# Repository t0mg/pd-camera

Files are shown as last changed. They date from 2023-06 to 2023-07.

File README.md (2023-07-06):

# PD-Camera project

PD-Camera is an unofficial, experimental accessory for [Panic Inc.](https://panic.com/)'s [Playdate](https://play.date) handheld console, which as the name hopefully suggests allows the device to record pictures as well as animated gifs, in whopping  1-bit color and QVGA (320x240) resolution. Kind of similar to the [1998 accessory for that other monochrome handheld device](https://en.wikipedia.org/wiki/Game_Boy_Camera) (which has 2-bit color and fewer pixels).

> **This repository contains the hardware and firmware of the PD-Camera accessory. The source for the companion app that runs on the Playdate itself can be found [here](https://github.com/t0mg/pd-camera-app).**

Here's a one minute intro video (click to watch).

Watch the project's trailer video on YouTube (https://www.youtube.com/watch?v=sbAL9xYFmcQ)

And a four minute demo that was part of [Tiny Yellow Machine](https://www.youtube.com/@TinyYellowMachine)'s Playdate Community Direct. Goes a bit more into details and shows video recording (click to watch).

Longer demo introducing video feature, as part of the TYM Community Direct (https://youtu.be/dU_6qfiDft4?t=1531)

## Disclaimer

This project is 
- not affiliated with nor endorsed by [Panic Inc.](https://panic.com/), 
- highly experimental,
- very hacky,
   - oh so hacky.

While I crashed my own Playdate countless times working on this, and it has survived so far, I cannot be held responsible for any damage, data loss, bad selfie, pandemic, etc. that might occur to you while playing with this project. Use this at your own risk. Thanks ❤️.

## How does it work? Why does it exist?

For more context on how this project came to be, you can find its devlog [on Playdate's Dev forum](https://devforum.play.date/t/playdate-oneil-camera/11043) and a deep dive into how it all works [here](dive.md).

Otherwise read on for an overview of each part.

## Hardware

### Configurations

The Playdate can be attached to the camera accessory in three distinct configurations: **cover**, **camera**, and **selfie**.

The accessory is holding onto the Playdate with small magnets. In **camera mode**. A USB C cable plugs into the console and disappears inside a "chin" in the bottom of the accessory. In **cover mode** the Playdate can be unplugged and flipped with its screen facing backwards, in order to lay flat and protect it during transport.

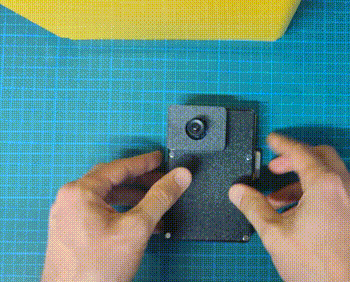
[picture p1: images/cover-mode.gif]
Transforming from cover mode to camera mode


The Playdate can also be fitted on the back of the accessory, without unplugging the cable, allowing to switch the camera to **selfie mode** (the companion app has a mirror option so it doesn't feel awkward). Additional magnets are here to secure the console in this configuration too.

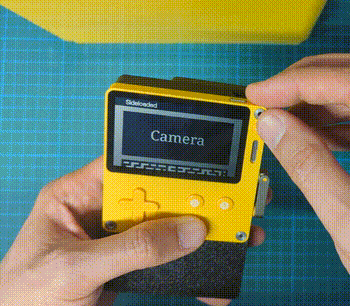
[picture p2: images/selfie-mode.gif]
Switching to selfie mode


### What's inside

The project is based on a [Teensy 4.1 microcontroller](https://www.pjrc.com/store/teensy41.html) that acts as a USB host to the Playdate and communicates with it over serial, including evaluating payloads in the Lua runtime (see [here](https://github.com/jaames/playdate-reverse-engineering/blob/main/usb/usb.md) for more details). The Teensy is also connected to an OV7670 camera module via its CMOS Sensor Interface (CSI) built into the IMXRT1062 MPU and using [this dedicated library](https://github.com/mjborgerson/OV7670). The images produced are 1-bit, QVGA (320x240 pixels) and recorded directly in the Playdate's filesystem. The Teensy takes care of dithering the images in various ways before sending them to the Playdate.

A battery, custom PCB and a custom 3D-printable case complete the hardware ([gerber](hardware/pcb) and [stl](hardware/case) files are provided in this repository).

For the detailed bill of material and assembly instructions, hop over to the [hardware folder](/hardware/).

## Firmware

To flash the Teensy microcontroller with the project's firmware, you'll need the [Teensy loader application](https://www.pjrc.com/teensy/loader.html). 

If you don't want to modify the source, you can directly grab a prebuilt `firmware.hex` file from the repository's [releases](https://github.com/t0mg/pd-camera/releases). Otherwise, read on to build your own.

## Companion app

The app that needs to be sideloaded onto the Playdate is located in a [separate repository](https://github.com/t0mg/pd-camera-app).

### Building

This project uses [PlatformIO](https://platformio.org/) to manage dependencies and build toolchain, see [platformio.ini](platformio.ini).

The source code comprises a single, messy [main.cpp](src/main.cpp) file, which relies on a few excellent libraries listed below.

## Credits

Dependencies
  -	[USBHost_t36](https://github.com/PaulStoffregen/USBHost_t36) by 
  [PaulStoffregen](https://github.com/PaulStoffregen)
  - [OV7670](https://github.com/mjborgerson/OV7670) by [mjborgerson](https://github.com/mjborgerson)
  - [dithering_halftoning](https://github.com/deeptronix/dithering_halftoning) by [deeptronix](https://github.com/deeptronix)

Made possible by
- https://github.com/jaames/playdate-reverse-engineering by [jaames](https://github.com/jaames)

 ----

 Playdate is © [Panic Inc.](https://panic.com/) - this project isn't affiliated with or endorsed by them in any way (just like [that one](https://github.com/jaames/playdate-reverse-engineering))

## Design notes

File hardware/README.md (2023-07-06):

This folder contains all files and instruction necessary to build the PD-Camera hardware.

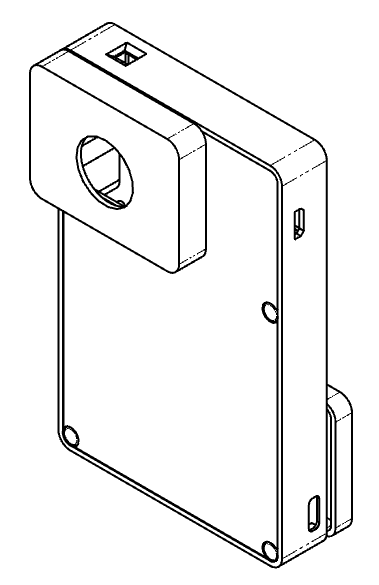
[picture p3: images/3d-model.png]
A drawing of the case from the OnShape project


## Bill of materials

Not counting the Playdate, the most expensive part here is the Teensy which retails for about 50€. The camera sensor is well under 10€. The PCB price will depend on the manufacturer but you can go very cheap too. Overall the whole project should cost around 100€ to build.

|Item| Quantity|Notes
|---|---|---|
|Custom PCB|1|Order from [JLCPCB](https://jlcpcb.com) or [OSH Park](https://oshpark.com/) see Gerber files
|Teensy 4.1 microcontroller| 1|[PJCRC store](https://www.pjrc.com/store/teensy41.html)
|OV7670 camera module|1|[Example (amazon.fr)](https://www.amazon.fr/dp/B07V1FCLXG?) ⚠️ these are AZDelivery brand. I found that similar boards with identical pinout sometimes differ in the orientation of the sensor and will not be compatible out of the box.
|Male headers, 24 pins |2 |0.1 inch (2.54 mm) spacing, for the Teensy
|Male headers,  4 or 5 pins |1 |0.1 inch (2.54 mm) spacing, for the Teensy's USB host port
|Female headers, 9pins | 2 | 0.1 inch (2.54 mm) spacing, for the camera module, to be cut from a standard length header
|Resistor 4k Ohm, through hole|2|
|Toggle switch SK12D07|1|
|Booster/charger USB C|1| The case is designed to fit this specific one from [aliexpress (5PCS 5V 2A USB)](https://a.aliexpress.com/_Ez5FiBT). For others you'll need to modify the 3D model before printing.
|3.7v LiPo battery|1| Should fit in the case (max size approx. 55 x 66 x 10 mm). I used a 5000 mAh battery I extracted from [this pack (amazon.fr)](https://www.amazon.fr/dp/B082PPR281).
|Neodymium magnets 5x5mm|8| Will hold the Playdate securly in place, [example (amazon.fr)](https://www.amazon.fr/dp/B00TACGMJW)
|Angled USB C to USB A cable|1|25 cm minimum; [example (amazon.fr)](https://www.amazon.fr/dp/B07H95NY5Y)
|PETG filament for the 3D printed parts 🙂|
|Some wires, solder...|
| *Optional:* CS mount & CS lenses || Read below

### CS and M12 mounts

Given that OV7670 boards are so cheap, I got 5 which allowed me to experiment with various  mounts and lenses. The case makes it deliberately easy to swap out the entire sensor board so you could have several with each a different lens and/or mount. Like a DSLR, except you also swap the sensor (no dust yay)!

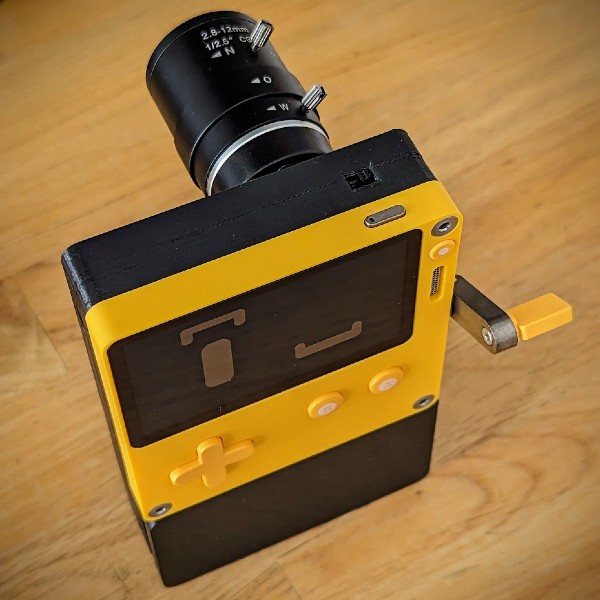
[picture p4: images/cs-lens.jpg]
A PD-Camera with a CS mount, telephoto lens. Admittedly looks cooler than with the default plastic lens.


Not all mounts are compatible and I had to do a bit of trial and error to find combinations of mounts and lenses that gives interesting results.

For the assembly pictured above, I bought [this CS mount (Aliexpress)](https://www.aliexpress.us/item/1005002055725137.html) and paired it with [this 2.8-12mm varifocal lens (Aliexpress)](https://www.aliexpress.us/item/3256802271188587.html).

Pay attention to the sensor distance of the mount. The first CS mount I purchased was too high, and the focal plane of the lenses hovered above the sensor, making it impossible to focus.

To replace the plastic mount that came with my OV7670 boards with this CS mount, I had to offset the screw holes a bit with a rotary tool, as pictured below.

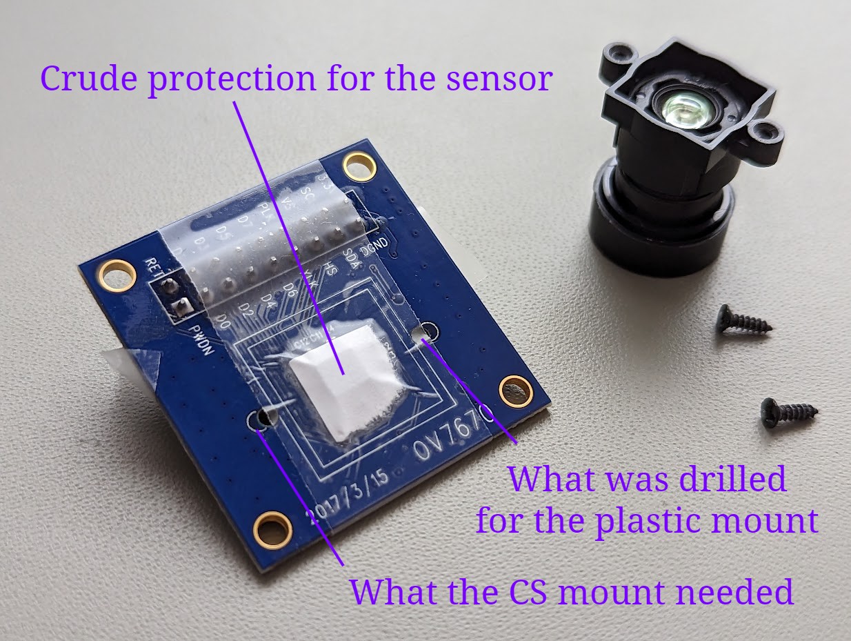
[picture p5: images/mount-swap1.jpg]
Fitting a new mount on one of my OV7670 boards
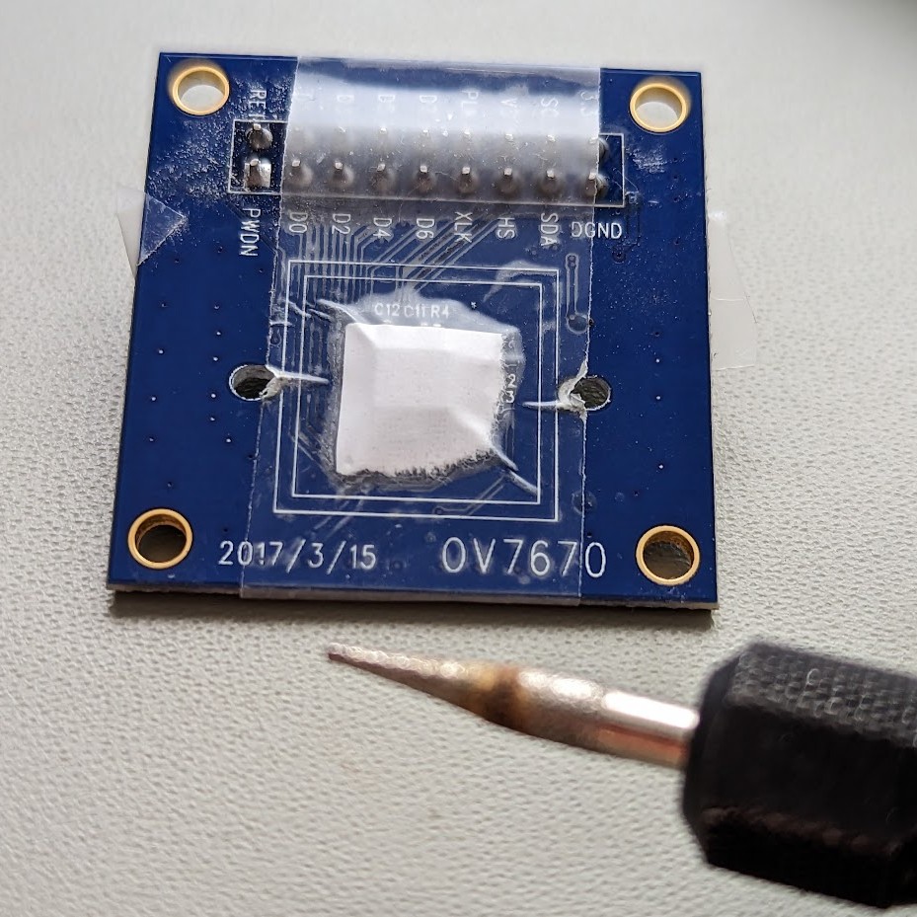
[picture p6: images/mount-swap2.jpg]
Making holes where the silkscreen suggests they should have been
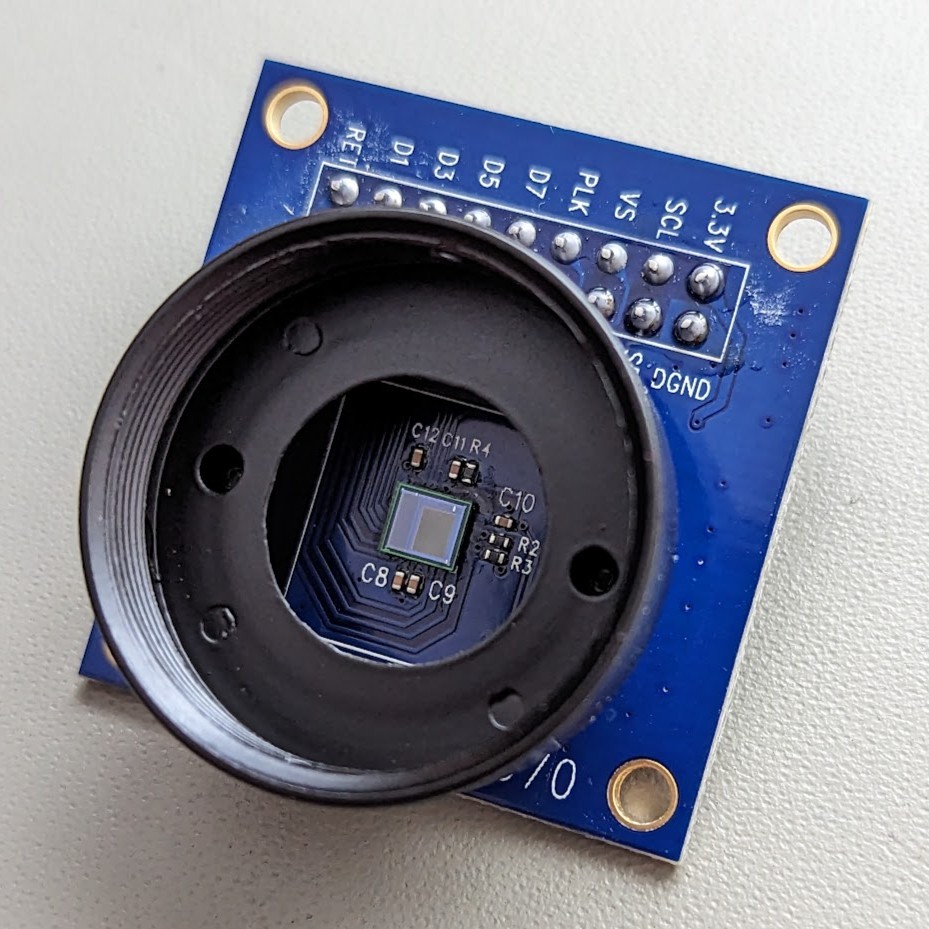
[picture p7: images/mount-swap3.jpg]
New CS mount secured to the sensor board
  

> Note: Pay attention to the orientation of the sensor. Some OV7670 boards have it swapped 90 or 180 degrees. The project is designed around this prarticular orientation. While 180 is fixable in the firmware code (setting register REG_MVFP), 90 degrees can not be used without significant modifications to the case and/or PCB.

These things being so cheap, I have plenty more to play with, including wide angle, a metal M12 mount and M12 lenses.

> // TODO: add more details here if there's interest, including example pictures and more references of tested lenses/mounts.

## Custom PCB

In order to keep the project small and easy to assemble, I designed a small PCB (my very first one so probably terrible, but it does work) to be paired with a custom designed case (which explains its peculiar shape). 

This is the wiring implemented by the PCB, it follows the documentation from the [OV7670 library](https://github.com/mjborgerson/OV7670) the project uses.

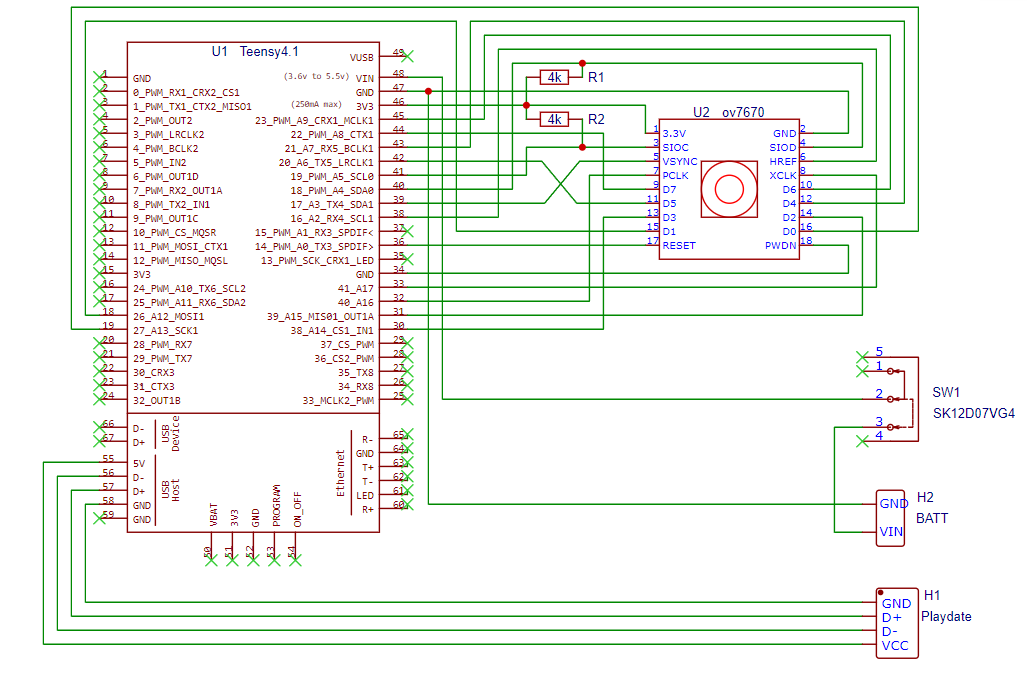
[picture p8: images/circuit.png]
Wiring circuit


The Gerber file for the PCB can be found [in the pcb folder](pcb/). It's 2 layer, standard thickness (1.57mm / 0.062 in). You can get one made from services such as [OSH Park](https://oshpark.com/) or [JLCPCB](https://jlcpcb.com/) for a few USD.

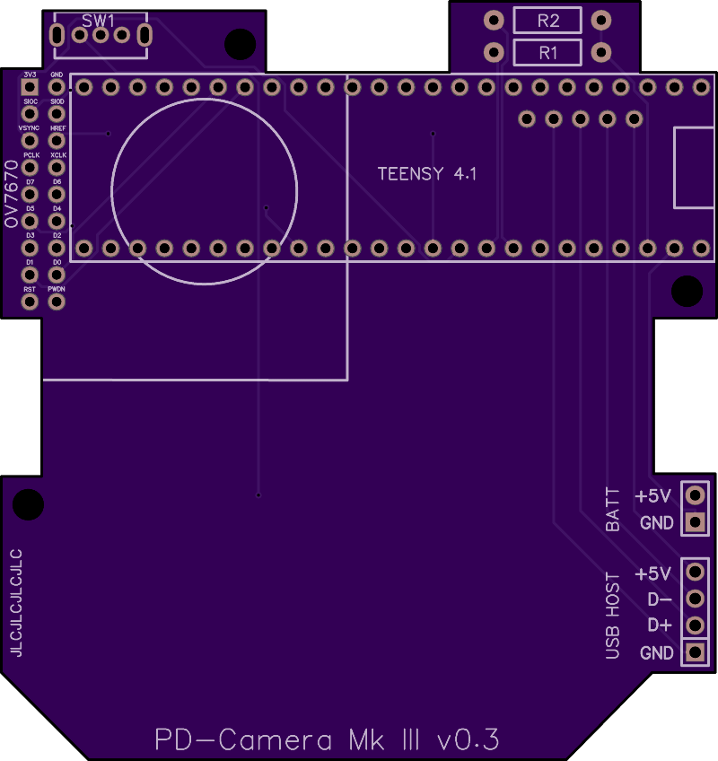
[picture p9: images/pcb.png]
A rendered view of the PCB


The large empty and seemingly useless part of the PCB is actually visible through button pockets on the face of the case, so the color you'll pick for the PCB matters. You can also customize the bottom silk screen with markings that will be visible when the Playdate is not installed!

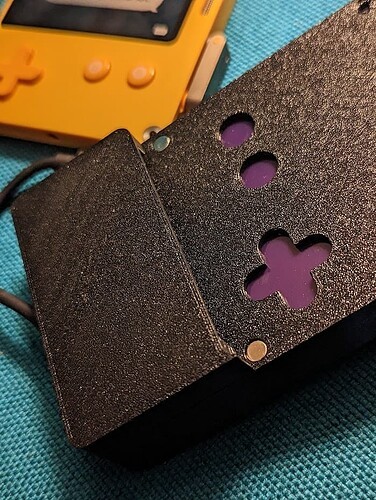
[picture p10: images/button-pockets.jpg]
A picture showing the button pockets on the 3D printed case and the purple PCB underneath


## Electronics assembly

Before do anything, plug the Teensy to a computer via its micro USB port and make sure the LED blinks, indicating the Teensy is working correctly. You can then take this opportunity to [flash the pd-camera firmware](../README.md#firmware).

> **WARNING**: If you want to be safe, you can now cut off the copper trace pictured below so the Teensy no longer draws power from its micro USB port. This eliminates the risk for the battery power to flow back into your computer if you connect the Teensy to it (in order to e.g. update the firmware).
>
> - If you cut the trace, you'll then need to turn the battery on even when plugging the Teensy's to a computer via micro USB, but it's foolproof. 
> - If you don't cut the bridge **you must always remember to turn the battery off**, as the Teensy will be powered via its micro USB port.
>
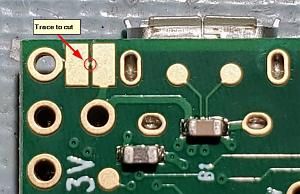
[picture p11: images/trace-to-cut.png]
Trace to cut to prevent micro USB from powering the Teensy (click for source)
> <p align="center"><a href="https://forum.pjrc.com/threads/70030-Teensy-4-1-Cut-pad-for-USB-location"></a/</p>  

### Soldering steps

Solder all male headers to the Teensy, including the 5 usb host pins. It helps to place the long headers on a breadboard to make sure the pins are straight (but you won't be able to do that with the USB Host pins because they're not aliged with the GPIO pins, so for these you can use the project's custom PCB).

Solder the 2 resistors and the toggle switch to the PCB.

Fit the Teensy flush onto the PCB, solder all pins and then cut off the protruding pins underneath, as short as possible.

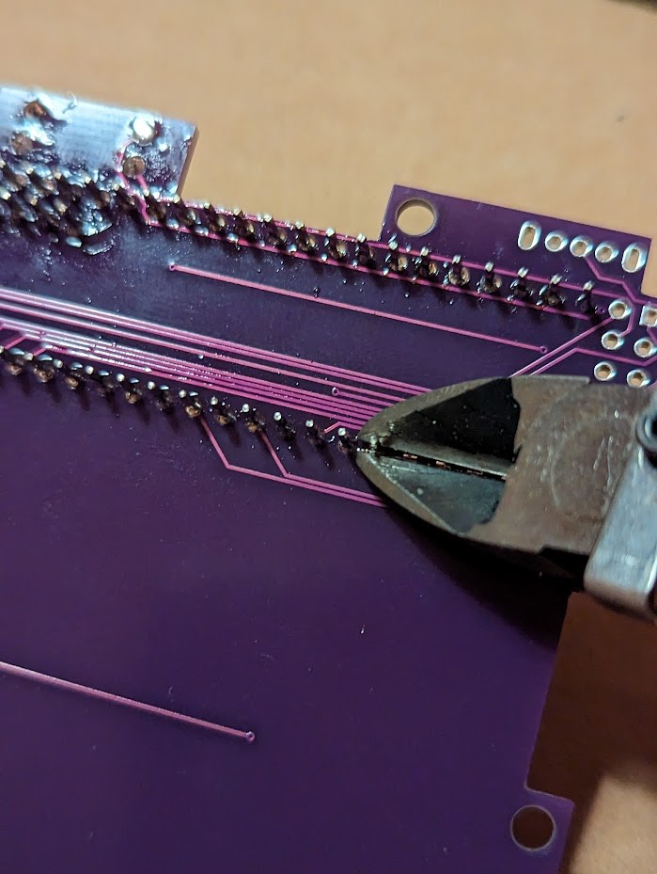
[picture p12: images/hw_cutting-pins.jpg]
Cutting Teensy pins flush


Cut 2 female header bars to 9 pins each and solder them to the PCB to create a makeshift connector for the OV7670 module.

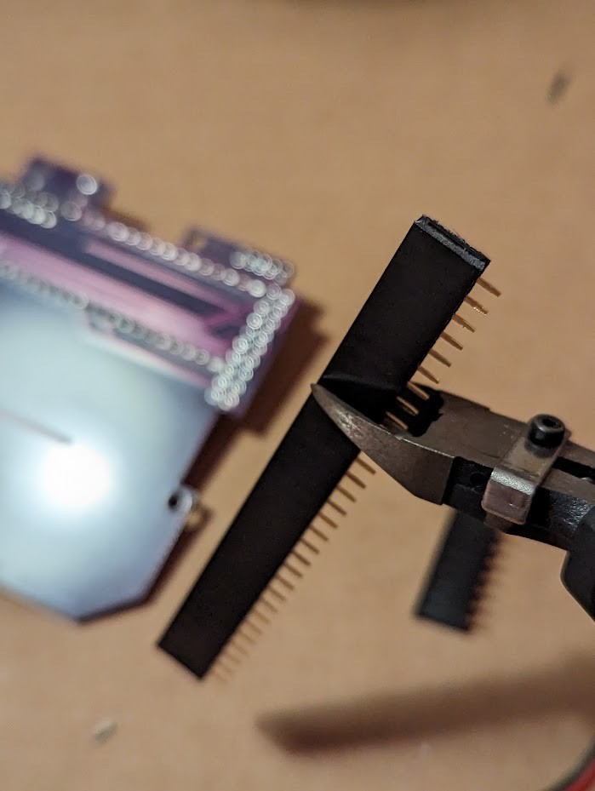
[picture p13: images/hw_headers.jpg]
Cutting female headers
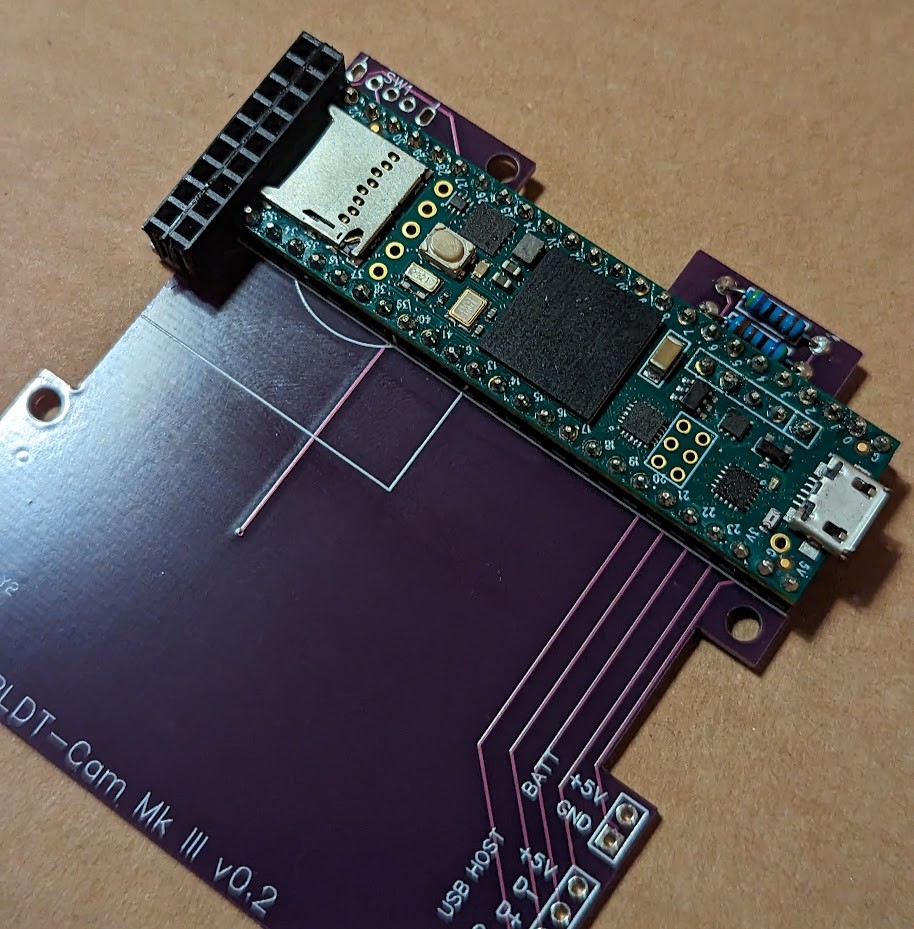
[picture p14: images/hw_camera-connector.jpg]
Camera module connector
 

Cut the angled USB C cable at about 25cm and discard the USB A connector. Strip and solder the 4 USB wires to the PCB (*usually*, red for +5v, white for D-, green for D+, and black for GND).

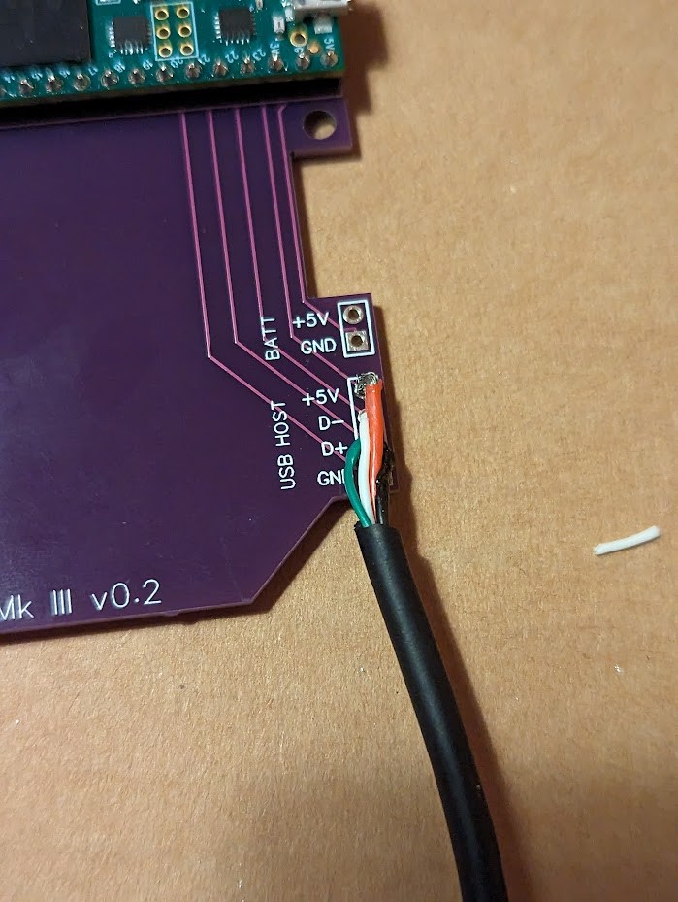
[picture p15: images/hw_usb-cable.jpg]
Soldering the USB Host cable


Solder BATT +5v and GND from the main PCB to the +5 and GND of the power circuit PCB with short wires, and finally solder the + and - battery pads of the power circuit to your LiPo battery. You can also do (or redo) this step after assembling the case in order to optimize your wiring.

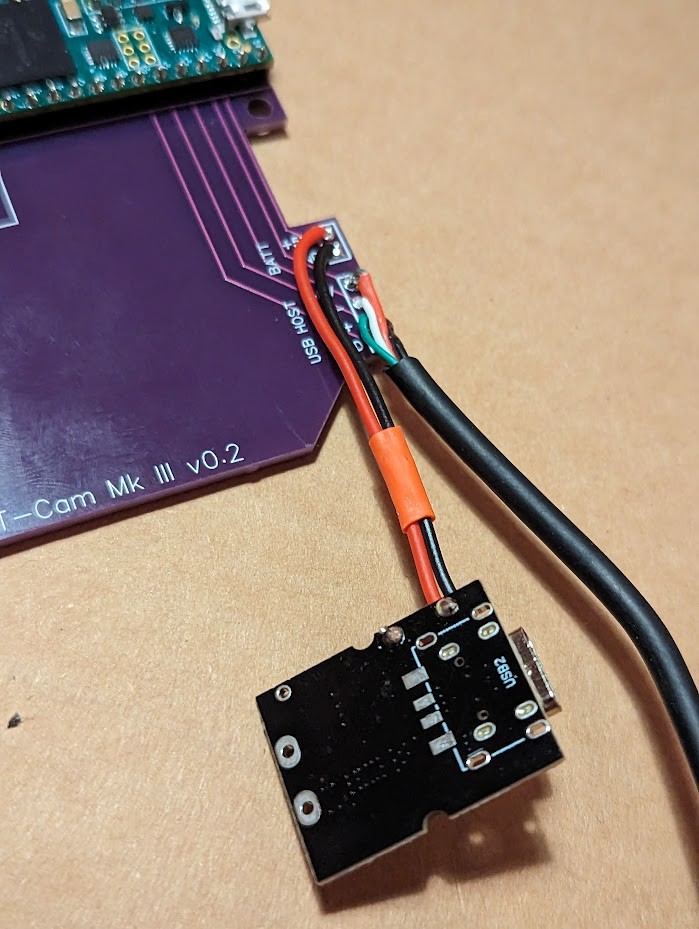
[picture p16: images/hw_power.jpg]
Soldering the power circuit


Almost done! Time to sideload the Playdate app (from [this repository](https://www.github.com/t0mg/pd-camera-app)) and test your circuit 🙂

Once you're confident with your solder joints, put your cutting pliers at work and make sure nothing protrudes underneath by more than a millimeter or so.

## 3D printed case

The case has 4 parts (body, chin, cover, camera cap) plus an optional flat spring that can help make the USB cable pop out of the chin. It was designed with OnShape (and Freecad orignally but I had to migrate).

Many iterations went into this design. The whole case could be more compact, especially with a smaller battery and fewer features. For example, without the selfie system the chin part could be reduced or removed, and the USB cable replaced with a simple dock connector. However I decided to prioritize versatility and ergonomics over compactness here.

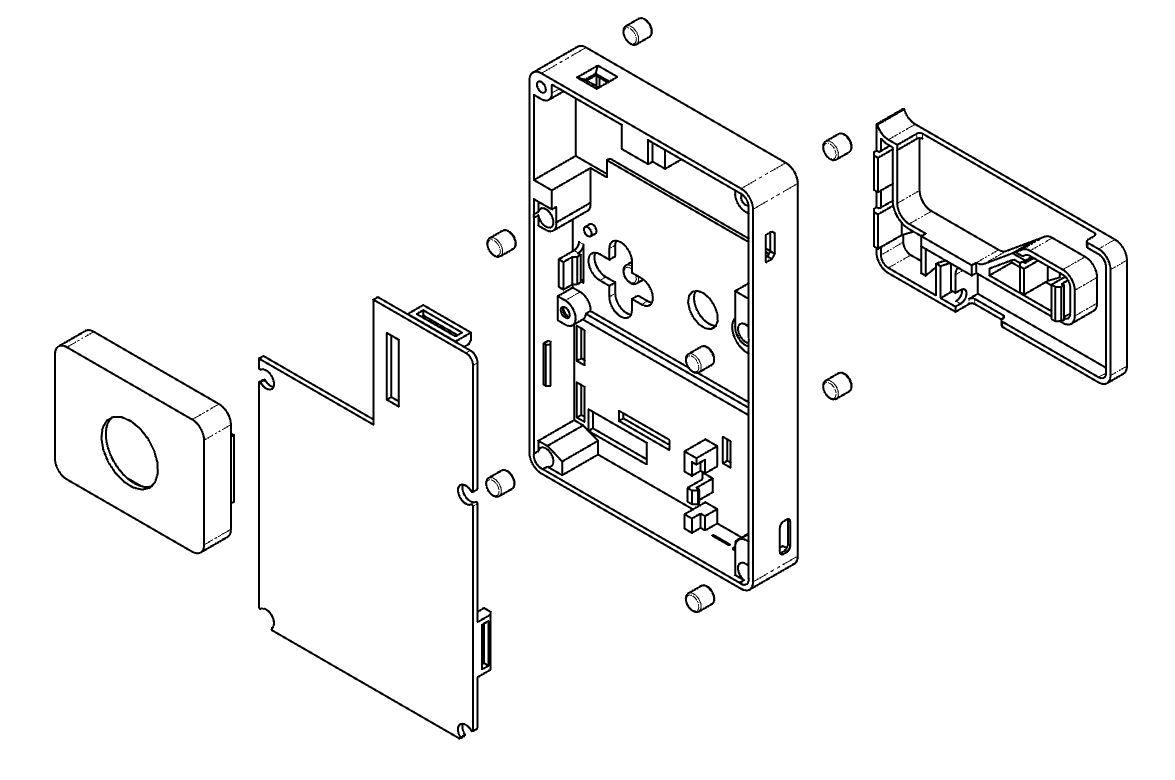
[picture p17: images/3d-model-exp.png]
Exploded view from the OnShape project showing all the parts


### Printing instructions

You can find the STL files [here](/hardware/case/). All the parts can be printed in one go on a Prusa Mk3S, in PETG at 0.2mm Speed mode, default settings. They were designed to print without support if you lay each part on its flat face. These are external facing sides that take advantage of a textured print bed for a better finish.

Printing takes about 4.5 hours and 61g of filament in total.

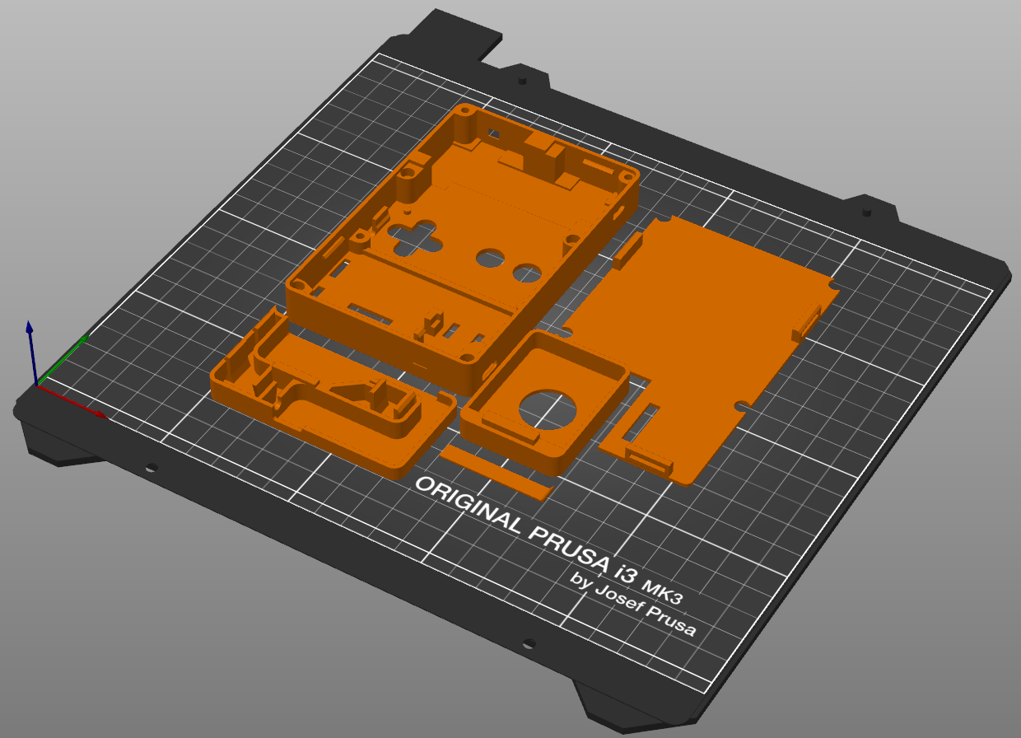
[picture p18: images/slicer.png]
Screenshot of all the parts in Prusa Slicer


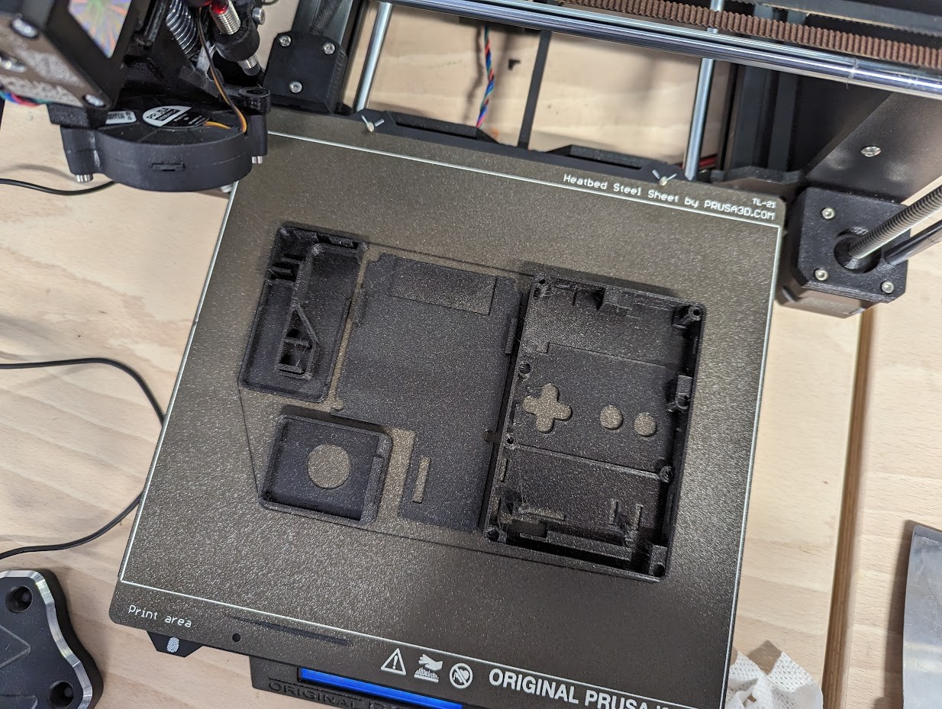
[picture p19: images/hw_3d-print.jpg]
Yes, I know, that print is not from the same Slicer project as above. It is from an older version.


### Editing the project files

Should you want to make changes, the entire source project is available publicly in OnShape [here](https://cad.onshape.com/documents/e21c7f87f60d07934982913d/w/b97fe7733e7e7384ebf3b9fe/e/61bb6eb626a207e4d2b47202).

## Putting it all together

The assembly doesn't require any screw or glue, and is fully reversible (mostly because during development, that was really useful).

### Installing the PCB

The PCB slides in and snaps without the need of any tool but it is a tight fit and requires a precise gesture and a bit of force. But don't be scared, the case is sturdy and my PETGs print survived way more assemblies and disassemblies than you should ever need to perform.

Start with the top of the PCB, fitting the little power switch through its hole in the case. Make sure the PCB is flush to the left side of the case, then lower its bottom part slowly. You'll now need to align the Teensy's USB port to the hole in the case on the right. Once it's aligned, push the PCB to the right so it gets in by a millimeter or so. Now press firmly on the PCB to snap it past the tiny leg on the right between USB and power wires, and then the snap lock on the bottom left. It's quite tight, but you can flex the edge of the case slightly outwards near the snap lock while pressing to help the PCB make it through.

### Power circuit

Slide the power circuit in place at a 45 degree angle. Insert the female USB C connector into its socket, then press the back of the board to lock it in place. It should be horizontal.

### USB Cable and chin

The male USB C connector goes through a dedicated hole. Keep the cable loose at this stage.

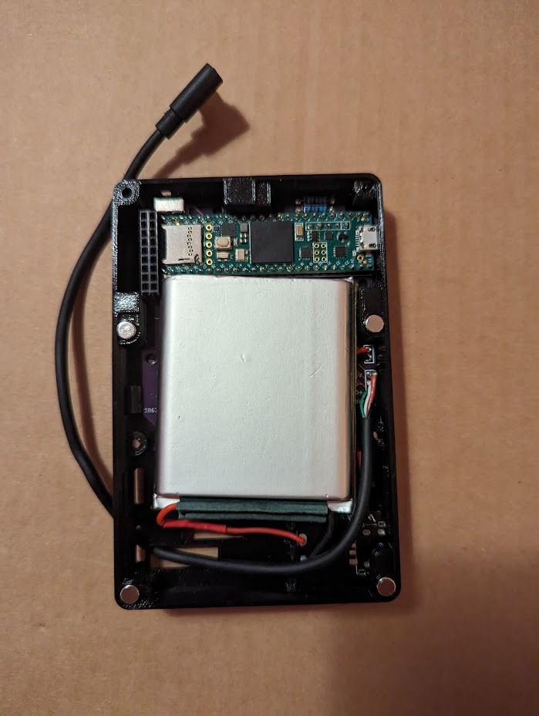
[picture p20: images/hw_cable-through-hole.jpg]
Passing the USB cable through its hole in the case


Flip the case and take the chin piece and your Playdate. Connect it, align it with the chin and work backwards to set the length of the cable.

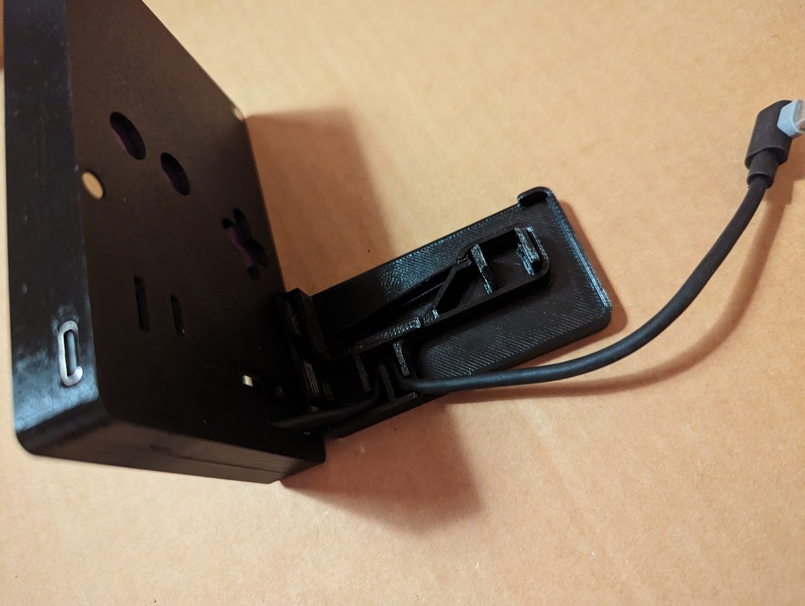
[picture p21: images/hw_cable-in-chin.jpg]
Locking the cable in the chin


You can add the optional spring part by just sliding it into the chin, this little piece helps when the cable is a bit too stiff to pop out naturally, but makes the "cover mode" a bit more difficult. Either way you can easily disassemble the case to add or remove this part later.

Snap fit the chin part into the main body part then flip it back and secure the remaining part of the USB cable.

### Battery

Now is the time to secure the battery and tidy all your wires inside the case. The 5000mAh battery fits (barely) under the Teensy, with its edges touching the Teensy and the right side of the connector of the camera module (as pictured [above](#usb-cable-and-chin)). 

### Cover

To put the cover, there are 3 snap fit locks to work with. First align the top one, then the right one. Finally flex the cover and push firmly on the left snap lock. To reopen the case you'd insert a spatula, blade or flat screw driver above the left snap lock and use it as a lever to free it.

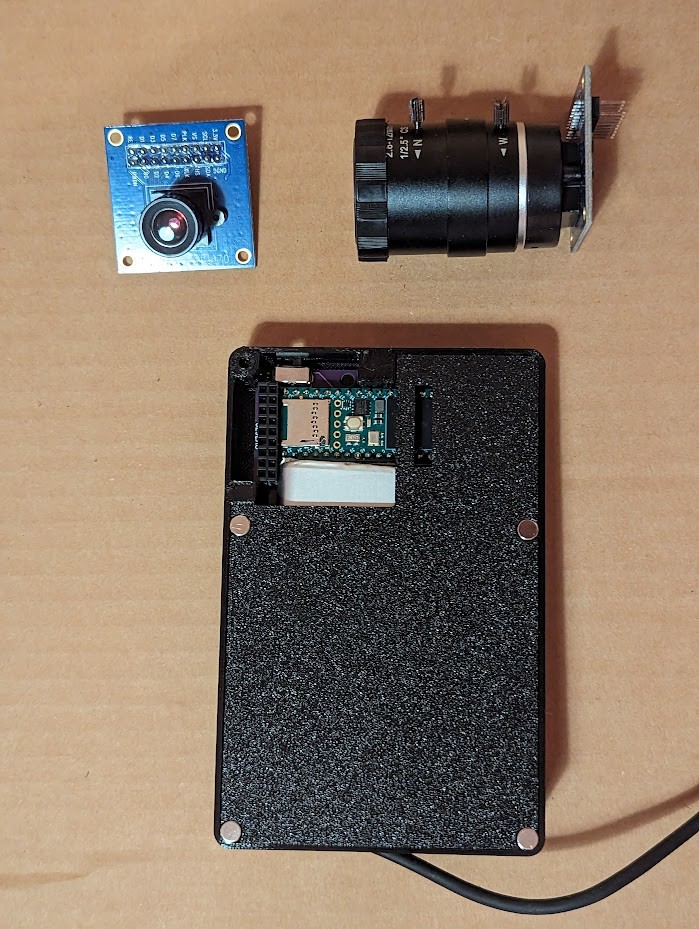
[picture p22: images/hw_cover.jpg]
Cover in place with camera modules ready to go


### Camera module and camera cap

You can insert the OV7670 Camera module now.

The camera cap part is also press fit. It comes off easily on purpose, so you can swap the camera module if you have different lens mounts, without having to remove the cover part. Otherwise, you can add a bit of super glue to attach the camera cap to the cover plate permanently.

There is currenlty no cap for larger mounts/lenses such as CS one in the photo above. I don't see this as a major issue as the sensor board holds itself just fine. But for polish reasons, in future updates we might add new caps with stronger fit (eg stap fit joints) and more opening sizes.

### Magnets

Press fit the eight neodymium magnets into their respective holes. I found that it helps to stack 2 of them to align with the hole and initiate a good vertical fit, then to use the handle of a fork or spoon to push the magnet all the way in. If they feel loose  you can add a drop of superglue to secure them (I never had to).

Should you need to reuse these magnets, the case is designed so that you can remove them, by pushing them from the back with a thin screwdriver for the 4 on the chin side, and by pulling them out with small pliers (and cover removed) for the 4 on the back side.

### Pat yourself in the back

Congratulation, you've built your own PD-Camera! 😊

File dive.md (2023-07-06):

# So, how does it all work?

## The origins

This project is built on the shoulders of my previous [playwrite project](https://github.com/t0mg/playwrite), in which I also used a [Teensy microcontroller](https://www.pjrc.com/store/teensy41.html) to connect gamepads and even keyboards to the Playdate without the need for a computer in-between (well, in reality the Teensy _is_ that computer).

At first sight this should not be possible, because the Playdate's USB port is a client, not a host. It would be like connecting a gamepad to a hard disk.

The catch is that the Playdate provides serial over USB, which is normally used by the SDK's Simulator app running on a computer to talk to the console (send game builds, debug, reboot, take screenshots, etc). So the Playdate is a client, the host being the computer.

The Teensy is also able to act as a USB host which enables many cool projects (you can plug all sorts of client devices like drives, controllers, bluetooth dongles, etc.). What's more, there's a [Serial USB library](https://github.com/PaulStoffregen/USBHost_t36) too, which meant that in theory a Teensy could connect to a Playdate and pretend to be a Simulator. This theory was already almost entirely validated by [jaames's awesome reverse engineering work](https://github.com/jaames/playdate-reverse-engineering).

In playwrite, the Teensy sends simple commands over serial to register gamepad inputs in the context of the Playdate. For the keyboard, which isn't normally supported, I used a little trick and encoded characters as crank rotations. So gamepads could be used with any Playdate app, but the keyboard required a dedicated app to interpret these crank moves as characters.

## How it started

For this project I took the general concept one step further and transmit a _lot_ more data to the Playdate. I hooked up a cheap OV7670 camera sensor to the Teensy thanks to its dedicated CMOS Sensor Interface (CSI) and [this library](https://github.com/mjborgerson/OV7670), configured its registers to provide monochrome pictures (actually YUV and zeroing out U and V) and processed this data through an [Arduino compatible dithering library](https://github.com/deeptronix/dithering_halftoning) I found, to reduce it from 256 shades of gray to either 1 or 0. The Teensy is powerful enough to handle all of this, especially since the OV7670 writes the framebuffers via CSI DMA channels (so, it's fast and cheap).

> Note: The pictures are QVGA (320x240) which fills the Playdate screen vertically but not horizontally - I ended up using the remaining 80 pixels for the UI. The OV7670 is actually capable of VGA pictures (640x480) so in theory we could crop into them and have full screen, slightly zoomed in images on Playdate. But this would require soldering extra PSRAM chips to the Teensy to make room for 4x larger frame buffers and I wanted to keep the project "simple" at least on the hardware side.

The very first prototype used the `bitmap` serial command allowing to display bitmap data on the playdate screen (it's a utility thing for developers to quickly test their mocks and artwork on a real display).

[It worked!](https://twitter.com/t0m_fr/status/1641205037136494592) But with a major caveat: this serial command really turns the console into a mere display: no code can run at the same time. You might be able to take a screenshot with the system menu but there is no room for custom UI. 

One option would've been to embrace the _"my Playdate is a display, your argument is invalid"_ philosophy, store pictures on the Teensy's SD card, and hook a few buttons and knobs to it for shutter and other controls. We could even render a UI overlay in the Teensy and send that to the display. Now there's also a way more complicated option, which I of course went with.

## How it's going

Jaames suggested that I try the eval command to send arbitrary Lua bytecode to be executed in the Playdate's currently running app (which would ba a dedicated one just like with the playwrite).

This involved generating a bytecode "template" which is a simple lua function call, eg. doSomething("0000"). Compiling this file, extracting the bitecode, isolating the zeroes and converting it into a C array hardcoded in the Teensy code. At runtime the teensy uses this template and replacea the zeroes with the data we want to send to the Playdate (it has to be the same number of bytes, e.g. "1234"). Then we craft the eval serial command with this payload. Effectively if all goes well this executes `doSomething("1234")` immediately in the Playdate's Lua context. All that's left to do is to actually declare a `function doSomething(data)` to process the paylod (display the image).

The actual payload for an image is 320x400 bits packed into 9600 8 bit chars, so the real lua template has 9600 zeroes in it. The code and instructions to create your own custom eval templates are [here](lua/README.md).

### But thats not all.

Fitst off we need a 2-way communication so each device can tell the other when theyre ready. For Teensy to Playdate there's an additional lua payload template ti transmit short status codes. For Playdate to lua its very easy: thanks to the SDK roots of the serial frature, all `print` calls in Lua ans C are sent to the serial host. So the Teensy needs to process formatted messages signifying "hey I'm here", "send me a picture" "switch dithering mode" or "lower brightness". This was already implemented for the playwrite project.

The current implementation of this 2-way communication is still quite crude but much more stable than what it once was. Still, it's currently reakly not advised to unplug the Playdate or put it to sleep while the camera is sending its feed. Ideally this could be extracted in a more robust, generic library that avoids message collisions with a proper queue system. That's significant work.

### That's still not all...

Decoding the string into a Playdate image object requires processing it bit by bit in a large for loop.

One lead to significantly improve FPS would be to generate image object bytecode on the Teensy side and eval it directly. That would allow us to skip the processing on the Playdate (which is significantly less powerful than the Teensy), at the cost of a larger payload tk transmit over serial. How much larger is a good question to try to answer.

But until someone takes up this task we had to turn our app into a C+Lua hybrid, so the Lua function passes the received data to a C funtion that does the image conversion and sends it back to Lua (amd I suspect there might be a memory leak somewhere, see [known issues in the companion app's repository](https://github.com/t0mg/pd-camera-app/README.md#known-issues)).

All in all it runs at about 3-4 fps and that's currently the speed of the "videos" we can record.

### Speaking of videos

Playdate can natively save an image as `.gif`, so we do that for stills. But we also save a `.pdi` (Playdate's proprietary image format) in order to be able to read it back in the camera roll (gifs are write-only). When you delete an image in the roll, it deletes both.

But videos ate another story. There is no way to encode a series of images as `.pdv` (Playdate's proprietary video format) or `.gif`. So what we do instead is save all the images in a temp folder, the use another C function to encode an animated `.gif` and write it on the file system. After each frame the C function passes over to Lua so it can display progress using yield (the whole thing has to run in the `playdate.update()` for this to work). Then we call C again to process the next frame, rinse and repeat.

And because this process is entirely manual, we are not limited to black & white: it is easy to set the 1-bit color palette to whatever we fancy (gray/grayer, purple/yellow, etc.) - and therefore I added a few options that are currently only available in video mode. We could bring this feature to still images if we used the algorithm instead of the built-in, write-only conversion provided by the SDK. Leaving that as an exercise to you, dear reader, as a reward for reading all of this.

## Fin

I think I've covered everything that isn't standard. The rest of the code Lua is just like a regular Playdate game and should be straightforward to understand.

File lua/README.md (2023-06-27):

This folder contains the Lua source files for the 2 functions that are hardcoded as bytecode in [main.cpp](../src/main.cpp), in order for the Teensy to evaluate payloads over serial in the Playdate's lua runtime (see [here](https://github.com/jaames/playdate-reverse-engineering/blob/main/usb/usb.md#eval) for details).

To generate tye bytecode:

  1) write lua function calls in a separate lua file (see [lua](/lua) folder). Add padding to make room for the data you'll need to transmit.
  2) compile the files to `.pdz` using Playdate SDK's `pdc`
  3) extract `.luac` with [this Python script](https://raw.githubusercontent.com/jaames/playdate-reverse-engineering/main/tools/pdz.py)

     e.g  `python pdz.py main.pdx\processMessage.pdz .`

  4) convert `.luac` to C byte array with [this tool](https://notisrac.github.io/FileToCArray/)
  5) paste into C source code and replace the padding with custom data (see  [main.cpp](../src/main.cpp))

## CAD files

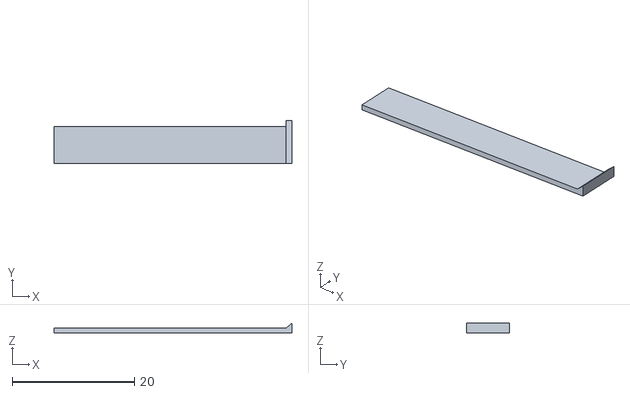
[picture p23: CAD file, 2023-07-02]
hardware/case/PD-Camera parts - Camera spring.stl
39.0 x 7.00 x 1.59

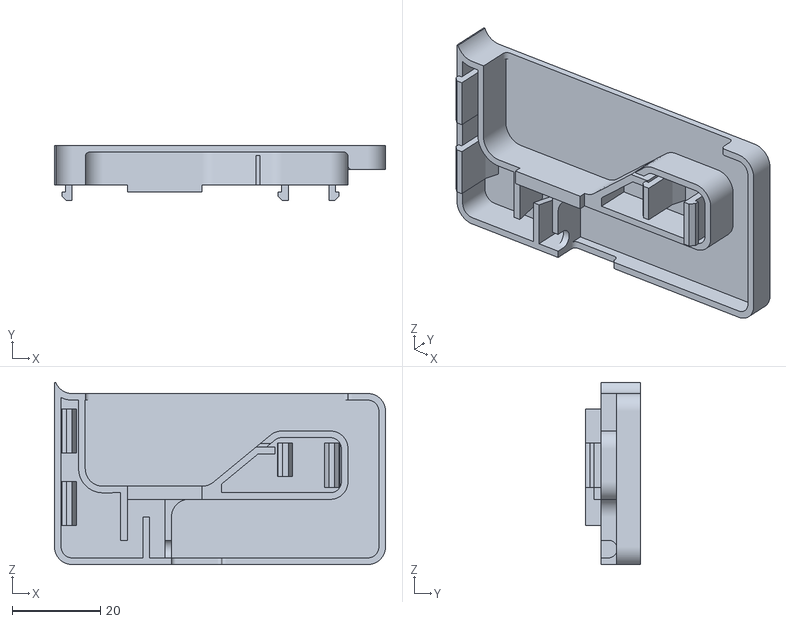
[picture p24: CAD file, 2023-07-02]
hardware/case/PD-Camera parts - Chin.stl
75.0 x 12.5 x 41.2

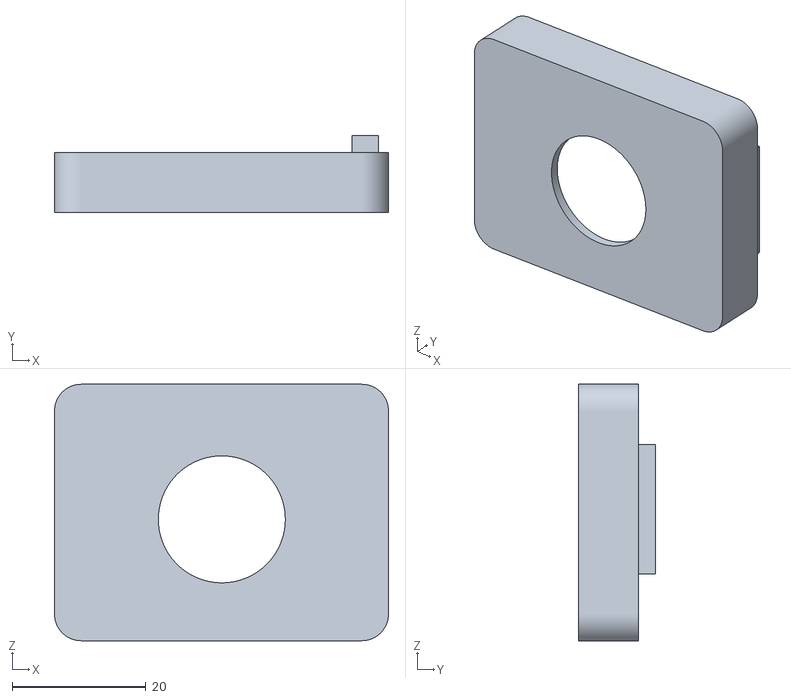
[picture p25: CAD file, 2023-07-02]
hardware/case/PD-Camera parts - Camera cap.stl
50.0 x 11.5 x 38.4

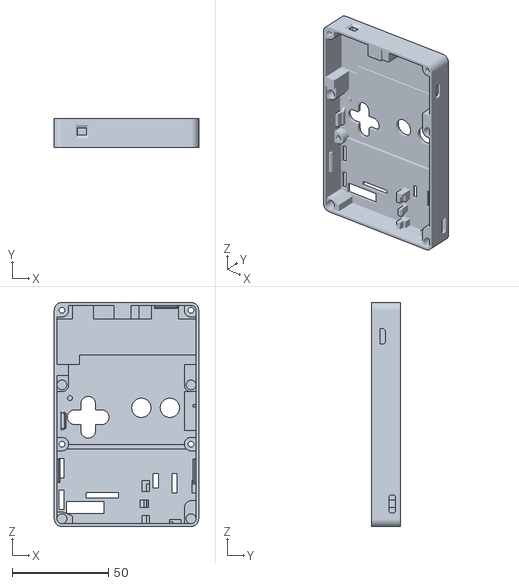
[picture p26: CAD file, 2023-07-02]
hardware/case/PD-Camera parts - Case body.stl
75.0 x 15.0 x 116.2

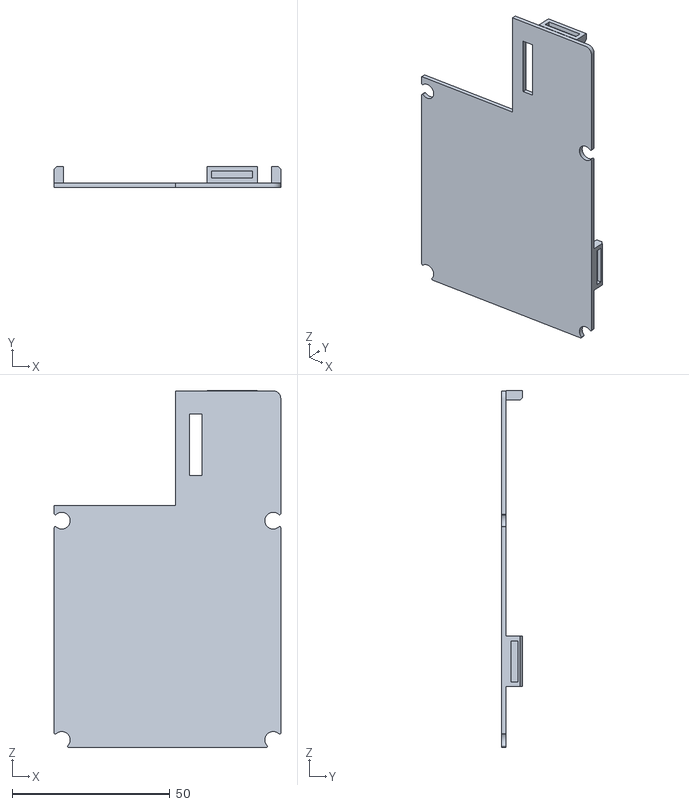
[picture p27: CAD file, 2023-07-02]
hardware/case/PD-Camera parts - Cover.stl
71.8 x 6.70 x 113.1

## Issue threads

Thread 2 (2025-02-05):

Seeking guidance for similar project

mindstormpro3, 2025-02-05:
Ever since I saw this project, I knew I needed to make something similar. I had an idea one day. “What if I made this, but instead of a camera you have Wi-Fi functionality?”

I absolutely love this project, and I want to create a universal system where the playdate talks to a Teensy 4.1, and the teensy talks to an ESP-32 or Arduino with Wi-Fi, and then sent back to the play date. I could make a custom library/package/thing for Lua on the playdate that automatically communicates with everything and allows for HTTP requests or stuff. This would allow online games and services!

I am not the best with coding though. If you could explain how the communication between the play date and the teensy 4.1 work, that would be great because I am relatively new to coding and would like to know how it all works.

Thanks,
Elio

t0mg, 2025-02-11:
Hi @mindstormpro3 ,

The details of how the pd-camera works are here:
https://github.com/t0mg/pd-camera/blob/main/dive.md

A couple of notes:

- you don't need both a Teensy and an ESP32. As a matter of fact a developer named abenokobo ported this project to ESP already: https://github.com/abenokobo/pd-camera-m5
- the `msg` command was introduced later in the Playdate SDK and should make things simpler, see the last few posts in [this forum thread](https://devforum.play.date/t/playwrite-a-hack-to-turn-the-playdate-into-a-typewriter-and-use-usb-controllers-with-the-console/8742/2)

Good luck!

Closed 2025-02-05.

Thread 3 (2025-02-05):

Seeking guidance for similar project

mindstormpro3, 2025-02-05:
Ever since I saw this project, I knew I needed to make something similar. I had an idea one day. “What if I made this, but instead of a camera you have Wi-Fi functionality?”

I absolutely love this project, and I want to create a universal system where the playdate talks to a Teensy 4.1, and the teensy talks to an ESP-32 or Arduino with Wi-Fi, and then sent back to the play date. I could make a custom library/package/thing for Lua on the playdate that automatically communicates with everything and allows for HTTP requests or stuff. This would allow online games and services!

I am not the best with coding though. If you could explain how the communication between the play date and the teensy 4.1 work, that would be great because I am relatively new to coding and would like to know how it all works.

Thanks,
Elio

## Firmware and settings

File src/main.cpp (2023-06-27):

// PD-Camera project by Tom Granger 
// Highly experimental, use at your own risk :)

#include <Arduino.h>
#include <EEPROM.h>
#include <Dither.h>
#include <OV7670.h>
#include <SD.h>
#include "USBHost_t36.h"

// Adds a ton of debug info to the Teensy's serial 
// including a mirror of the Playdate's serial output.
// #define DEBUG 1

#ifdef DEBUG
#define DEBUG_PRINT(x) Serial.println(x)
#else
#define DEBUG_PRINT(x)
#endif

const int ledpin = 13;
const char *PLAYDATE_PRODUCT_NAME = "Playdate";
const unsigned int MAX_INPUT = 80;
elapsedMillis sinceLastMessage;
uint32_t baud = 115200;
USBHost myusb;
USBHub hub1(myusb);
USBSerial_BigBuffer userial(myusb, 1);

USBDriver *drivers[] = {&hub1, &userial};
#define CNT_DEVICES (sizeof(drivers) / sizeof(drivers[0]))
const char *driver_names[CNT_DEVICES] = {"Hub1", "USERIAL1"};
bool driver_active[CNT_DEVICES] = {false, false};

//  Put all the buffers in DMAMEM
uint8_t fcaptbuff[320l * 240l * 2] DMAMEM;
uint8_t cbuff1[320l * 240l * 2] DMAMEM;
uint8_t cbuff2[320l * 240l * 2] DMAMEM;
Dither image(320, 240);

const char compileTime[] = " Compiled on " __DATE__ " " __TIME__;

#define LEDON digitalWriteFast(ledpin, HIGH); // Also marks IRQ handler timing
#define LEDOFF digitalWriteFast(ledpin, LOW);

void blinkN(int times)
{
  for (int i = 0; i < times; i++)
  {
    delay(200);
    LEDON;
    delay(200);
    LEDOFF;
  }
}

void blinkForever(void)
{
  while (1)
  {
    blinkN(1);
  }
}

const int pinCamReset = 14;

// Dither library overrides
#define fastEDDither_remove_artifacts true
#define _size 4

enum CameraStatus {
  INITIALIZING,
  AWAITING_CONNECTION,
  CONNECTED,
  FRAME_REQUESTED,
  SENDING_FRAME,
};

CameraStatus status = INITIALIZING;

enum DitherType
{
  STUCKI,
  ATKINSON,
  FS,
  FAST,
  BAYER,
  RNDM,
  THRESHOLD
};

DitherType currDitherType = STUCKI;
uint8_t thresh = 128;

/*
  These are the 2 Lua functions sent by the Teensy via eval command.
  See https://github.com/t0mg/pd-camera-hardware/lua/readme.md for details.
*/
static const int statusCharIndex = 87;
static const int evalStatusCodeLength = 107;
static const byte evalStatusCode[evalStatusCodeLength] PROGMEM = {
    27, 76, 117, 97, 84, 0, 25, 147, 13, 10, 26, 10, 4, 4, 4, 120,
    86, 0, 0, 0, 64, 185, 67, 1, 147, 64, 112, 114, 111, 99, 101, 115,
    115, 83, 116, 97, 116, 117, 115, 46, 108, 117, 97, 128, 128, 0, 1, 2,
    133, 79, 0, 0, 0, 9, 0, 0, 0, 131, 128, 0, 0, 66, 0, 2,
    1, 68, 0, 1, 1, 130, 4, 142, 95, 99, 97, 109, 101, 114, 97, 83,
    116, 97, 116, 117, 115, 4, 130, 49, 129, 1, 0, 0, 128, 133, 1, 0,
    0, 0, 0, 128, 128, 129, 133, 95, 69, 78, 86};

enum StatusCode
{
  INIT = 48,         // 0 in ASCII
  READY = 49,        // 1
  STREAMING = 50,    // 2
  OK = 51,           // 3
  ERROR = 52         // 4
};

void sendStatusCode(StatusCode code)
{
  byte statusMessage[evalStatusCodeLength];
  memcpy(statusMessage, evalStatusCode, evalStatusCodeLength);
  statusMessage[statusCharIndex] = code;
  userial.flush();
  userial.println("eval 107");
  userial.write(statusMessage, evalStatusCodeLength);
  sinceLastMessage = 0;
}

static const int headerLength = 86;
static const byte evalPayloadHeader[headerLength] PROGMEM = {
    27, 76, 117, 97, 84, 0, 25, 147, 13, 10, 26, 10, 4, 4, 4, 120,
    86, 0, 0, 0, 64, 185, 67, 1, 146, 64, 112, 114, 111, 99, 101, 115,
    115, 73, 109, 97, 103, 101, 46, 108, 117, 97, 128, 128, 0, 1, 2, 133,
    79, 0, 0, 0, 9, 0, 0, 0, 131, 128, 0, 0, 66, 0, 2, 1,
    68, 0, 1, 1, 130, 4, 141, 95, 99, 97, 109, 101, 114, 97, 73, 109,
    97, 103, 101, 20, 75, 129}; // for 320x240 (QVGA) image
// 93, 225}; for 400x240 image

static const int footerLength = 19;
static const byte evalPayloadFooter[footerLength] PROGMEM = {
    129, 1, 0, 0, 128, 133, 1, 0, 0, 0,
    0, 128, 128, 129, 133, 95, 69, 78, 86};

static const int imageWidth = 320;
static const int imageHeight = 240;
static const int packedImageLength = imageWidth * imageHeight / 8;
static const int payloadLength = headerLength + packedImageLength + footerLength;
char evalCommand[12];

void processImage(void)
{
  if (status != FRAME_REQUESTED) {
    return;
  }
  status = SENDING_FRAME;
  uint32_t imagesize = OV7670.ImageSize();

  OV7670.ClearFrameReady();
  // wait until cbuff2 is ready
  while (OV7670.FrameReady() != 2)
  {
  }
  // pack Y values at the first half of the buffer
  for (uint32_t i = 0u; i < imagesize / 2; i++)
  {
    fcaptbuff[i] = cbuff2[2 * i];
  }
  // apply dithering to the first half of the buffer
  switch (currDitherType)
  {
  case STUCKI:
    image.StuckiDither(fcaptbuff);
    break;
  case ATKINSON:
    image.AtkinsonDither(fcaptbuff);
    break;
  case FS:
    image.FSDither(fcaptbuff);
    break;
  case FAST:
    image.fastEDDither(fcaptbuff);
    break;
  case BAYER:
    image.patternDither(fcaptbuff);
    break;
  case RNDM:
    image.randomDither(fcaptbuff, false);
    break;
  default:
    image.thresholding(fcaptbuff, thresh);
    break;
  }
  // pack the image as 1bit in a new byte array
  byte payload[payloadLength];
  memcpy(payload, evalPayloadHeader, headerLength);
  memcpy(&payload[headerLength + packedImageLength], evalPayloadFooter, footerLength);
  int byteIndex = headerLength;
  int pixelIndex = 0;
  int bufferIndex = 0;
  while (byteIndex < headerLength + packedImageLength)
  {
    byte currentByte = 0;
    for (int n = 7; n >= 0; n--)
    {
      uint8_t val = fcaptbuff[bufferIndex++];
      if (val == 0u)
      {
        // clear bit at byteindex
        currentByte &= ~(1 << n);
      }
      else
      {
        // set bit at byteindex
        currentByte |= (1 << n);
      }
      pixelIndex++;
      pixelIndex = pixelIndex % imageWidth;
    }
    payload[byteIndex++] = currentByte;
  }
  if (status != SENDING_FRAME)
  {
    return;
  }
  userial.flush();
  userial.println(evalCommand);
  userial.write(payload, payloadLength);
  sinceLastMessage = 0;
  status = CONNECTED;
}

void processUpdatedDeviceListInfo()
{
  for (uint8_t i = 0; i < CNT_DEVICES; i++)
  {
    if (*drivers[i] != driver_active[i])
    {
      if (driver_active[i])
      {
#ifdef DEBUG
        Serial.printf("*** Device %s - disconnected ***\n", driver_names[i]);
#endif
        driver_active[i] = false;
        if (strcmp(driver_names[i], "USERIAL1") == 0)
        {
          status = INITIALIZING;
          blinkN(3);
          // sendStatusCode(INIT);
          // userial.end();
        }
      }
      else
      {
        driver_active[i] = true;
        const uint8_t *product = drivers[i]->product();
#ifdef DEBUG
        Serial.printf("*** Device %s %x:%x - connected ***\n", driver_names[i], drivers[i]->idVendor(), drivers[i]->idProduct());
        const uint8_t *psz = drivers[i]->manufacturer();
        if (psz && *psz)
          Serial.printf("  manufacturer: %s\n", psz);
        if (product && *product)
          Serial.printf("  product: %s\n", product);
        psz = drivers[i]->serialNumber();
        if (psz && *psz)
          Serial.printf("  Serial: %s\n", psz);
#endif
        // If this is a new Serial device.
        if (drivers[i] == &userial) //&& strcmp((const char *)product, PLAYDATE_PRODUCT_NAME) == 0)
        {
          DEBUG_PRINT("\nConnected to Playdate Serial, yay!");
          blinkN(1);
          status = AWAITING_CONNECTION;
          userial.begin(baud);
        }
      }
    }
  }
}

bool prefix(const char *pre, const char *str)
{
  return strncmp(pre, str, strlen(pre)) == 0;
}

const char *dataWithPrefix(const char *prefix, const char *string)
{
  int prefix_length = strlen(prefix);
  int string_length = strlen(string);

  if (prefix_length > string_length)
  {
    return NULL;
  }

  for (int i = 0; i < prefix_length; i++)
  {
    if (string[i] != prefix[i])
    {
      return NULL;
    }
  }

  return string + prefix_length;
}

void process_data(const char *data)
{
#ifdef DEBUG
  Serial.print("[Playdate] ");
  Serial.println(data);
#endif
  // Early exit if this is not a Camera command message.
  if (!prefix("Camera:", data))
  {
    return;
  }

  sinceLastMessage = 0;
  // Basic Camera commands.
  if (strcmp(data, "Camera:connect") == 0)
  {
    // if (status == AWAITING_CONNECTION)
    // {
      sendStatusCode(READY);
      status = CONNECTED;
    // }
    return;
  }
  else if (strcmp(data, "Camera:readyForNextFrame") == 0)
  {
    sendStatusCode(STREAMING);
    status = FRAME_REQUESTED;
    return;
  }
  else if (strcmp(data, "Camera:disconnect") == 0)
  {
    status = AWAITING_CONNECTION;
    return;
  }

  // Dithering mode setting.
  const char *ditherMode = dataWithPrefix("Camera:dither:", data);
  if (ditherMode != NULL)
  {
    if (strcmp(ditherMode, "stucki") == 0)
    {
      DEBUG_PRINT("Switching to Stucki dithering");
      currDitherType = STUCKI;
      // sendStatusCode(OK);
    }
    else if (strcmp(ditherMode, "atkinson") == 0)
    {
      DEBUG_PRINT("Switching to Atkinson dithering");
      currDitherType = ATKINSON;
      // sendStatusCode(OK);
    }
    else if (strcmp(ditherMode, "fs") == 0)
    {
      DEBUG_PRINT("Switching to Floyd-Steinberg dithering");
      currDitherType = FS;
      // sendStatusCode(OK);
    }
    else if (strcmp(ditherMode, "fast") == 0)
    {
      DEBUG_PRINT("Switching to Fast Error Diffusion dithering");
      currDitherType = FAST;
      // sendStatusCode(OK);
    }
    else if (strcmp(ditherMode, "random") == 0)
    {
      DEBUG_PRINT("Switching to random dithering");
      currDitherType = RNDM;
      // sendStatusCode(OK);
    }
    else if (strcmp(ditherMode, "bayer") == 0)
    {
      DEBUG_PRINT("Switching to bayer patterned dithering");
      currDitherType = BAYER;
      // sendStatusCode(OK);
    }
    else if (strcmp(ditherMode, "threshold") == 0)
    {
      DEBUG_PRINT("Switching to thresholding");
      currDitherType = THRESHOLD;
      // sendStatusCode(OK);
    }
    else
    {
      DEBUG_PRINT("Unknown dither mode requested");
      sendStatusCode(ERROR);
    }
    return;
  }

  // Contrast setting.
  const char *constrastStr = dataWithPrefix("Camera:contrast:", data);
  if (constrastStr != NULL)
  {
    int contrastValue = atoi(constrastStr);
    if (contrastValue > 0 && contrastValue < 256)
    {
      OV7670.SetContrast(contrastValue);
      // sendStatusCode(OK);
      return;
    }
    sendStatusCode(ERROR);
    return;
  }

  // Brightness setting.
  const char *brightnessStr = dataWithPrefix("Camera:brightness:", data);
  if (brightnessStr != NULL)
  {
    int brightnessValue = atoi(brightnessStr);
    if (brightnessValue > 0 && brightnessValue < 256)
    {
      OV7670.SetBrightness(brightnessValue);
      // sendStatusCode(OK);
      return;
    }
    sendStatusCode(ERROR);
    return;
  }

  // Threshold setting.
  const char *thresholdStr = dataWithPrefix("Camera:threshold:", data);
  if (thresholdStr != NULL)
  {
    int thresholdValue = atoi(thresholdStr);
    if (thresholdValue > 0 && thresholdValue < 256)
    {
      thresh = thresholdValue;
      // sendStatusCode(OK);
      return;
    }
    sendStatusCode(ERROR);
    return;
  }

  // Mirror (selfie mode) setting.
  const char *mirrorStr = dataWithPrefix("Camera:mirror:", data);
  if (mirrorStr != NULL)
  {
    int mirrorValue = atoi(mirrorStr);
    if (mirrorValue == 1 || mirrorValue == 0)
    {
      OV7670.WriteRegister(REG_MVFP, MVFP_FLIP + MVFP_MIRROR * abs(mirrorValue - 1));
      // sendStatusCode(OK);
      return;
    }
    sendStatusCode(ERROR);
    return;
  }
}

// from http://www.gammon.com.au/serial
void processIncomingByte(const byte inByte)
{
  static char inputLine[MAX_INPUT];
  static unsigned int inputPos = 0;

  switch (inByte)
  {
  case '\n':                   // end of text
    inputLine[inputPos] = 0; // terminating null byte
    // terminator reached! process inputLine here ...
    process_data(inputLine);
    // reset buffer for next time
    inputPos = 0;
    break;
  case '\r': // discard carriage return
    break;
  default:
    // keep adding if not full ... allow for terminating null byte
    if (inputPos < (MAX_INPUT - 1))
      inputLine[inputPos++] = inByte;
    break;
  } // end of switch

} // end of processIncomingByte

void setup()
{
  sprintf(evalCommand, "eval %d", payloadLength);
  image.buildBayerPattern();

  myusb.begin();

  Serial.begin(115200);
  delay(200);
  Wire.begin();

  pinMode(pinCamReset, OUTPUT);
  pinMode(ledpin, OUTPUT);

  digitalWriteFast(pinCamReset, LOW);
  delay(10);
  digitalWriteFast(pinCamReset, HIGH); // subsequent resets via SCB

#ifdef DEBUG
  // while (!Serial)
  // ; // wait for Arduino Serial Monitor
  Serial.printf("\n\nPlaydate Camera adapter %s\n", compileTime);
#endif

  if (OV7670.begin(QVGA, cbuff1, cbuff2))
  {
    OV7670.SetOutMode(YUV422);
    OV7670.WriteRegister(REG_TSLB, 1 << 4);
    OV7670.WriteRegister(0x67, 0);
    OV7670.WriteRegister(0x68, 0);
    OV7670.WriteRegister(REG_MVFP, MVFP_FLIP + MVFP_MIRROR);
    OV7670.ShowCamConfig();
    OV7670.ShowCSIRegisters();
#ifdef DEBUG
    Serial.println("OV7670 camera initialized.");
    Serial.printf("cbuff1 at   %p\n", cbuff1);
    Serial.printf("cbuff2 at    %p\n", cbuff2);
    Serial.printf("fcaptbuff at %p\n", fcaptbuff);
#endif
  }
  else
  {
#ifdef DEBUG
    Serial.println("Error initializing OV7670");
#endif
    blinkForever();
  }

#ifdef DEBUG
  OV7670.ShowCamConfig();
#endif

  LEDOFF
}

void loop()
{
  myusb.Task();
  processUpdatedDeviceListInfo();

  // Send requested image to the Camera app.
  if (status == FRAME_REQUESTED)
  {
    processImage();
  }
  // Let the Camera app know we're ready to send bytes.
  else if (sinceLastMessage >= 1000 && status != CONNECTED) {
    sinceLastMessage = sinceLastMessage - 1000;
    // sendStatusCode(READY);
  }

  // Monitor Playdate serial and process incoming messages.
  if (status != INITIALIZING) {
    while (userial.available() > 0)
      processIncomingByte(userial.read());
  }

}

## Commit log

2023-06-28 gerber files, BOM and assembly instructions
2023-06-28 fixed a couple of typos
2023-07-02 added disclaimer, bom updates
2023-07-02 stl files, new gerber revision, wote more doc
    [PD-Camera parts - Camera cap.stl, PD-Camera parts - Camera spring.stl, PD-Camera parts - Case body.stl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]
2023-07-05 small edits around cs mount notes
2023-07-05 Add a note on total cost of BOM
2023-07-05 typo due to fat fingers
